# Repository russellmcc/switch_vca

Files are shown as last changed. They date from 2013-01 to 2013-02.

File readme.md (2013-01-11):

This is an experimental design for a switched-mode VCA for eurorack format modular synthesizers.  It's intended to be a cheap replacement for a traditional OTA-based VCA.

This work is licensed under a [Creative Commons Attribution-ShareAlike 3.0 Unported License.](http://creativecommons.org/licenses/by-sa/3.0/deed.en_US)

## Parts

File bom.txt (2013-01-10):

Capacitors:
1x 0603 27pF  C0G capacitor 1% (C106)
1x 0603 68pF  C0G capacitor 1% (C104)
1x 0603 82pF  C0G capacitor 1% (C103)
1x 0603 100pF C0G capacitor (C101)
1x 0603 100pF ceramic cap   (C102) (any ceramic will do)
1x 0603 180pF C0G capacitor 1% (C105)
6x 0603 .1uF  X7R capacitor (C601, C602, C603)
1x 0805 1uF   X7R capacitor (C701)
1x 1206 10uF  Y5V capacitor (C702)

Semiconductors
1x SOD-323  Schottky Diode   (D701)
1x SOT-23   Enhancement P-channel MOS (Q101)
1x SOT-23   N-channel JFET (Q102)
1x SOT23-5  NCV551SN50T1G 5V LDO (IC301)
1x SOP-14   LM319 Comparator (U101)
2x SOIC-8   LF353 Op amp (U102, U103)

Resistors
1x  0603 3.0  Resistor 5% (R102)
1x  0603 1k   Resistor 5% (R111)
2x  0603 10k  Resistor 5% (R103, R701)
1x  0603 47k  Resistor 5% (R303)
4x  0603 100k Resistor 1% (R107, R108, R109, R110)
7x  0603 100k Resistor 5% (R104, R105, R106, R301, R302, R304, R403)
1x  0603 330k Resistor 5% (R401)

Connectors
3x Erthenvar Jack
1x MO8x2     Eurorack power connector
1x MO5x2     Piggy Connector Male
1x MO5x2     Piggy Connector Female

Potentiometers
2x PDB12 100K PCB mount panel pot (PDB12-H4251-104BF)

Switches
1x SPDT switch PCB mount

Mouser order:
https://www.mouser.com/ProjectManager/ProjectDetail.aspx?AccessID=782688147c

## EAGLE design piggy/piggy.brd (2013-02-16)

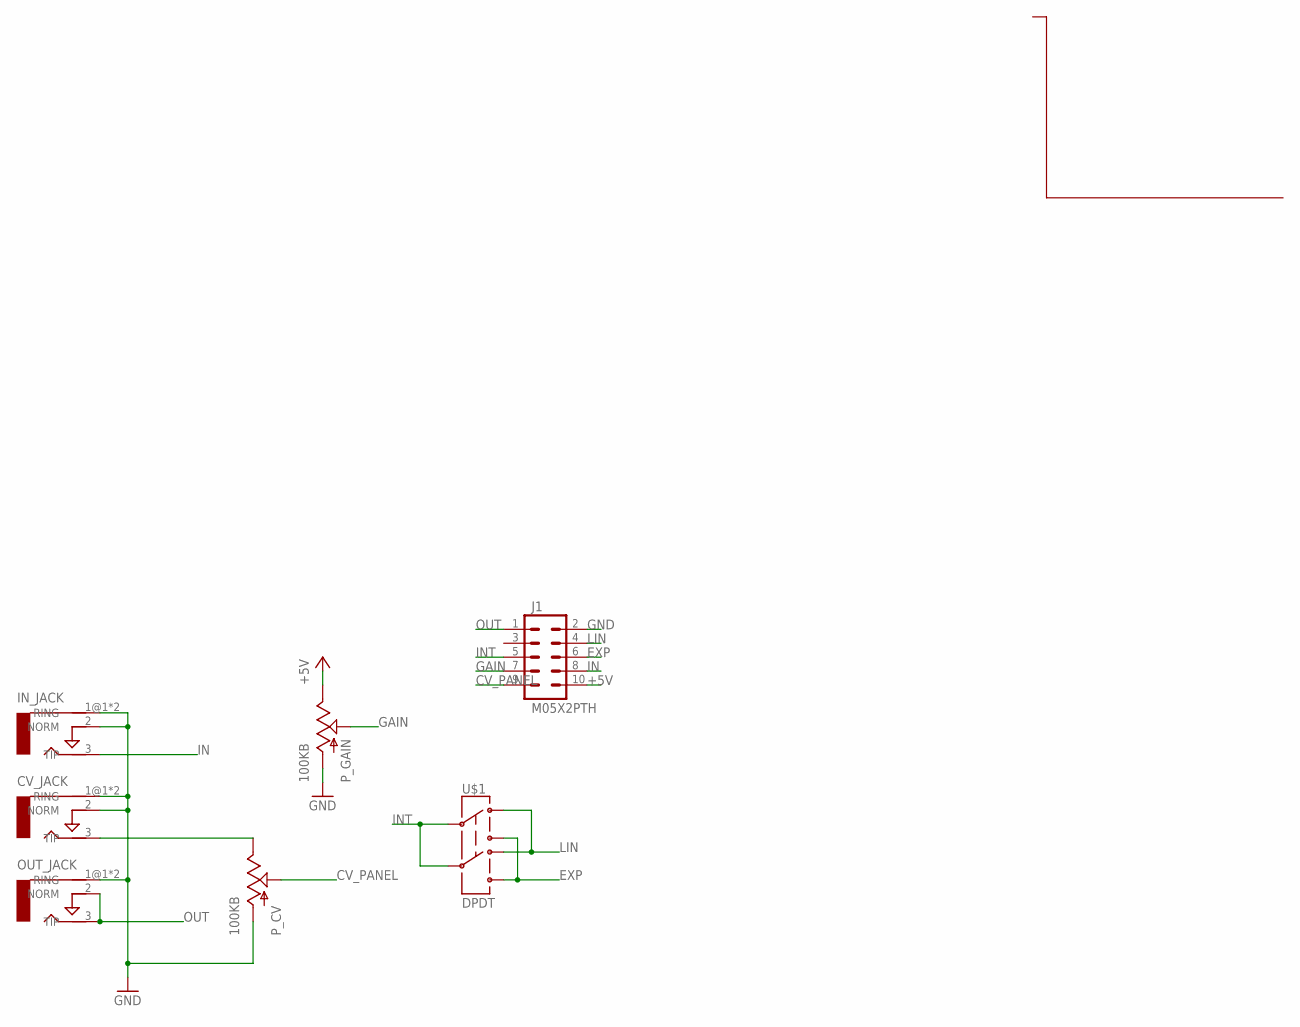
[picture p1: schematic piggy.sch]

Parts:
CV_JACK: AUDIO-JACKERTHENVAR; ERTHENVAR-JACK
IN_JACK: AUDIO-JACKERTHENVAR; ERTHENVAR-JACK
J1: M05X2PTH; AVR_ICSP
OUT_JACK: AUDIO-JACKERTHENVAR; ERTHENVAR-JACK
P_CV: 100KB; PDB12
P_GAIN: 100KB; PDB12
U$1: DPDT; MOUNTAIN_10SL005

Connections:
+5V: J1.10, P_GAIN.3 (E)
CV_PANEL: J1.9, P_CV.2 (S)
EXP: J1.6, U$1.Y1, U$1.Y2
GAIN: J1.7, P_GAIN.2 (S)
GND: CV_JACK.1@1 (RING), CV_JACK.1@2 (RING), CV_JACK.2 (NORM), IN_JACK.1@1 (RING), IN_JACK.1@2 (RING), IN_JACK.2 (NORM), J1.2, OUT_JACK.1@1 (RING), OUT_JACK.1@2 (RING), P_CV.1 (A), P_GAIN.1 (A)
IN: IN_JACK.3 (TIP), J1.8
INT: J1.5, U$1.C1, U$1.C2
LIN: J1.4, U$1.X1, U$1.X2
unnamed: CV_JACK.3 (TIP), P_CV.3 (E)
OUT: J1.1, OUT_JACK.2 (NORM), OUT_JACK.3 (TIP)

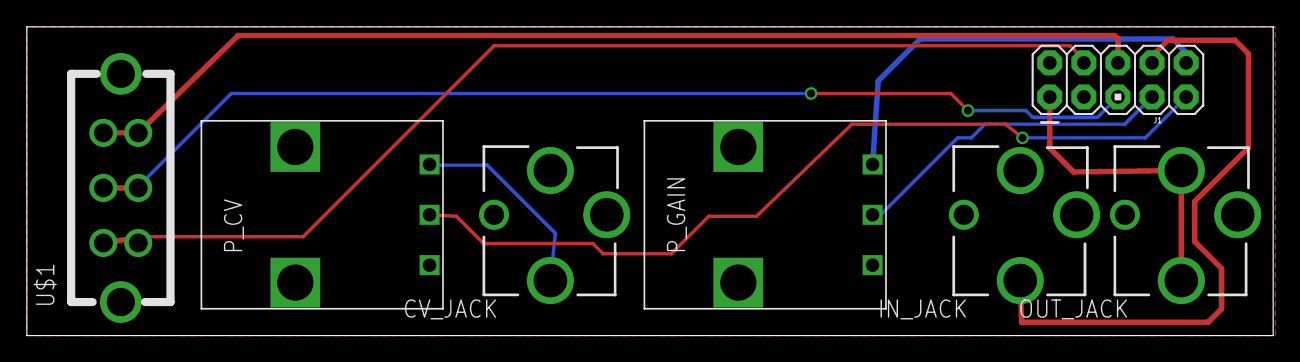
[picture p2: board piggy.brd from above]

Board: 2 copper layers, 92.8 x 23.0 mm, 7 parts (0 on the bottom side), 10 nets.

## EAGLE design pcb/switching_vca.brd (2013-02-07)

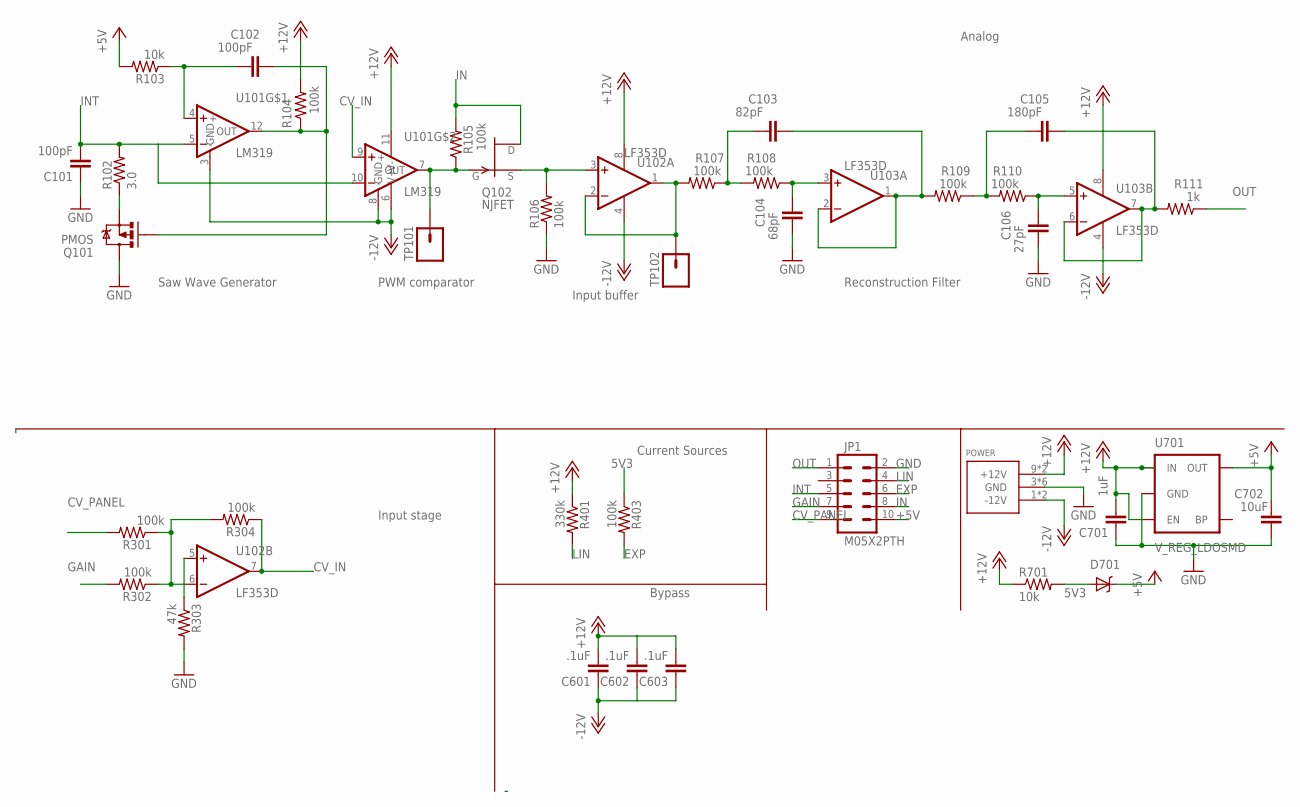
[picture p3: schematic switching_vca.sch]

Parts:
C101, C102: 100pF; 0603-CAP
C103: 82pF; 0603-CAP
C104: 68pF; 0603-CAP
C105: 180pF; 0603-CAP
C106: 27pF; 0603-CAP
C601, C602, C603: .1uF; 0603-CAP
C701: 1uF; 0805
C702: 10uF; 1206
D701: DIODE-SCHOTTKY; SOD-323
JP1: M05X2PTH; AVR_ICSP
POWER: POWER_SIMPLE16; POWER_16
Q101: PMOS; SOT23-3
Q102: NJFET; SOT23
R102: 3.0; 0603-RES
R103, R701: 10k; 0603-RES
R104, R105, R106, R107, R108, R109, R110, R301, R302, R304, R403: 100k; 0603-RES
R111: 1k; 0603-RES
R303: 47k; 0603-RES
R401: 330k; 0603-RES
TP101, TP102: M01PTH; 1X01
U101: LM319; SOP-14
U102, U103: LF353D; SO08
U701: V_REG_LDOSMD; SOT23-5

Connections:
5V3: D701.1 (A), R403.1, R701.2
+5V: C702.1, D701.2 (C), JP1.10, R103.2, U701.5 (OUT)
+12V: C601.2, C602.2, C603.2, C701.2, POWER.9 (+12V), POWER.10 (+12V), R104.2, R401.1, R701.1, U101.11 (V+), U102.8 (V+), U103.8 (V+), U701.1 (IN), U701.3 (EN)
-12V: C601.1, C602.1, C603.1, POWER.1 (-12V), POWER.2 (-12V), U101.3 (GND), U101.6 (V-), U101.8 (GND), U102.4 (V-), U103.4 (V-)
CV_IN: R304.1, U102.7 (OUT)
CV_PANEL: JP1.9, R301.2
EXP: JP1.6, R403.2
GAIN: JP1.7, R302.2
GND: C101.1, C104.2, C106.2, C701.1, C702.2, JP1.2, POWER.3 (GND), POWER.4 (GND), POWER.5 (GND), POWER.6 (GND), POWER.7 (GND), POWER.8 (GND), Q101.3 (D), R106.1, R303.2, U701.2 (GND)
IN: JP1.8, Q102.1 (D), R105.2
INT: C101.2, JP1.5, R102.2, U101.5 (-), U101.10 (-)
LIN: JP1.4, R401.2
N$: C102.1, Q101.1 (G), R104.1, U101.12 (OUT)
unnamed: Q101.2 (S), R102.1
unnamed: Q102.3 (G), R105.1, TP101.1, U101.7 (OUT)
unnamed: C102.2, R103.1, U101.4 (+)
unnamed: C103.1, R109.2, U103.1 (OUT), U103.2 (-IN)
unnamed: Q102.2 (S), R106.2, U102.3 (+IN)
unnamed: C103.2, R107.1, R108.2
unnamed: C104.1, R108.1, U103.3 (+IN)
unnamed: R303.1, U102.5 (+IN)
unnamed: C105.2, R109.1, R110.2
unnamed: C106.1, R110.1, U103.5 (+IN)
unnamed: C105.1, R111.2, U103.6 (-IN), U103.7 (OUT)
unnamed: R107.2, TP102.1, U102.1 (OUT), U102.2 (-IN)
OUT: JP1.1, R111.1
R301: R301.1, R302.1, R304.2, U102.6 (-IN)

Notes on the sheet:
Saw Wave Generator
PWM comparator
Reconstruction Filter
Analog
Input stage
Current Sources
Bypass
Input buffer

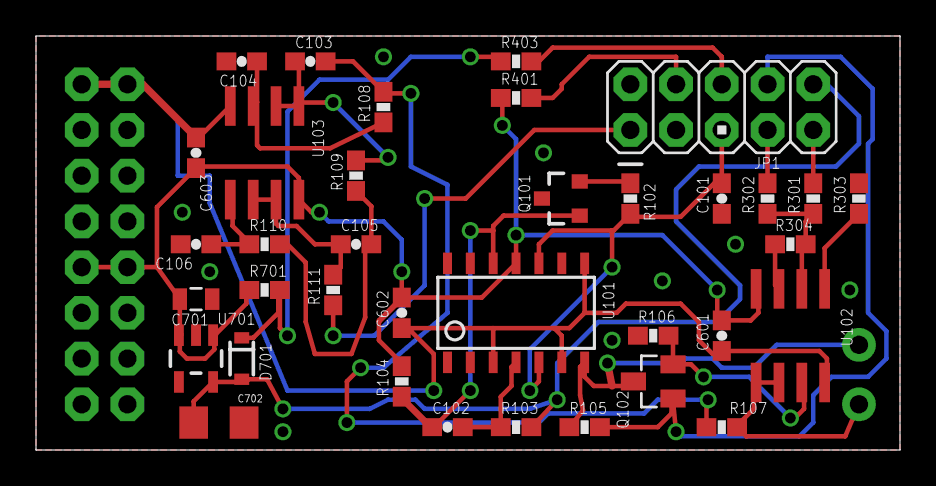
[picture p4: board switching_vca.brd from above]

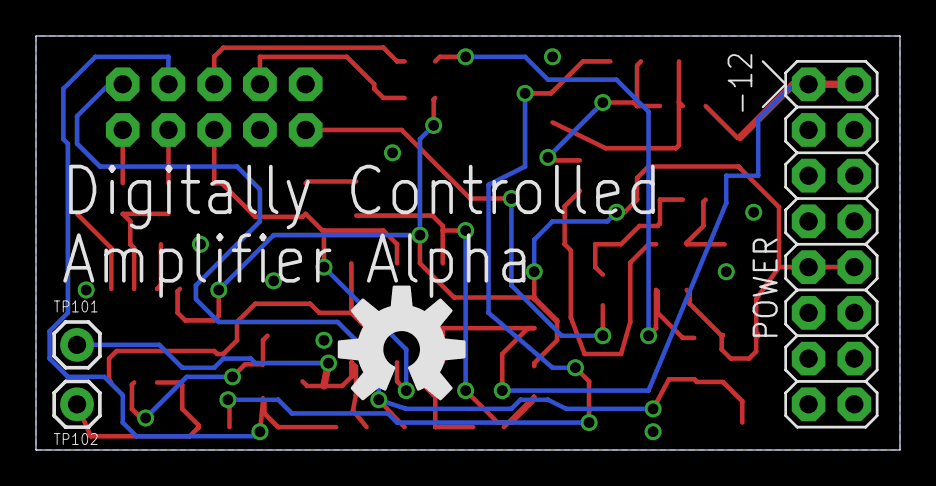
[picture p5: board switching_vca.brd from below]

Board: 2 copper layers, 48.0 x 23.0 mm, 40 parts (4 on the bottom side), 27 nets.

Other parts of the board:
U$1: OSHW-LOGO-L

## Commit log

2013-01-03 added some simulations
    [switching_vca.sch]
2013-01-06 found a fast comparator so remove the level conversion stage of the switch simulation
    [switching_vca.sch]
2013-01-07 First attempt at schem (footprints not specced), initial BOM
    [switching_vca.sch]
2013-01-10 added shitty board, made mouser bom
    [switching_vca.brd, switching_vca.sch]
2013-01-11 Routed the board with a travesty of VIAs
    [switching_vca.brd, switching_vca.sch]
2013-01-11 Added a piggy back board
    [piggy.brd, piggy.sch]
2013-01-11 aligned jacks to pot origin
    [piggy.brd]
2013-01-17 Laid out panel.
    [piggy.brd]
2013-01-27 hole placement
    [piggy.brd]
2013-02-07 added test point for PWM comparator output
    [switching_vca.brd, switching_vca.sch]
2013-02-16 fixed footprint/front panel
    [piggy.brd, piggy.sch]

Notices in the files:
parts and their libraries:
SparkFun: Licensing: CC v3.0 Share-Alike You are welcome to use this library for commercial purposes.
